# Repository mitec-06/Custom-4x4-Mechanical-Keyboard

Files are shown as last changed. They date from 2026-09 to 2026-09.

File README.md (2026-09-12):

# Custom 4x4 Keyboard PCB Design

This project is a custom 4x4 mechanical keyboard PCB featuring USB HID firmware on RP2040, addressable RGB LEDs (SK6812) driven via PIO state machine, rotary encoder brightness control, and HSV color animation functions.

## Functions

### Core Functions

- 16 keys arranged in a 4 x 4 matrix pattern.

- 6 key rollover - up to 6 simultaneous keypresses registered.

- USB HID keyboard output - It can work as a plug-and-play keyboard on any computer.

- Debouncing key detection - Prevents false or double triggers from a mechanical switch bounce.

- Diode per key - Diodes were included for every key in order to prevent ghosting.

### LED Functions
- Idle RGB ripple animation - Outward ripple effect starting from center rings cycling through the entire HSV color spectrum.

- Keypress-reactive LEDS - Animation switches to keypress mode when any key is pressed, returns to idle afterwards.

- Full HSV color transition - Smooth transition between red, orange, yellow, green, cyan, blue, magenta and back.

- Ring based animation - Three concentric rings with slight phase offset creating a ripple appearance.

- Brightness control - Using a rotary encoder, smooth brightness scaling from 0-100% applied uniformly to all LEDs.

- Brightness preserved across all animation modes, whether its idle or a key is being pressed.

### Encoder Functions 

- Clockwise rotation increases brightness, counterclockwise rotation decreases brightness.

- Hardware debouncing edge detection - Prevents any skips when rotating the encoder.

### Hardware Features 

- 3.3V to 5V level shifting for LED data signal via SN74LV1T34

- Daisy-chained SK6812 MINI-E LEDs driven via RP2040 PIO state machine.

- RP2040 PIO state machine - Dedicated programmable Input/Output handles precise WS2812 timing independent of CPU timing.

- WS2812 protocol followed to ensure correct latch reset timing.

- USB powered - single cable for both HID and power communication.

## Timeline

### April 2026 - May 2026

Primarily worked on keyboard research, and drafting the schematic and pcb. Once the pcb was finished, spent some time revising the placement of parts on the board to make sure that there were no shorts or awkward placements that would make assembly difficult.

Schematic

PCB Layout

### May 2026 - June 2026

Ordered the first batch of PCBs from PCBWay, and begun soldering the first prototype, however several hardware bugs prevented the LEDs from functioning properly, causing odd behavior, and allowing only the typing to work.

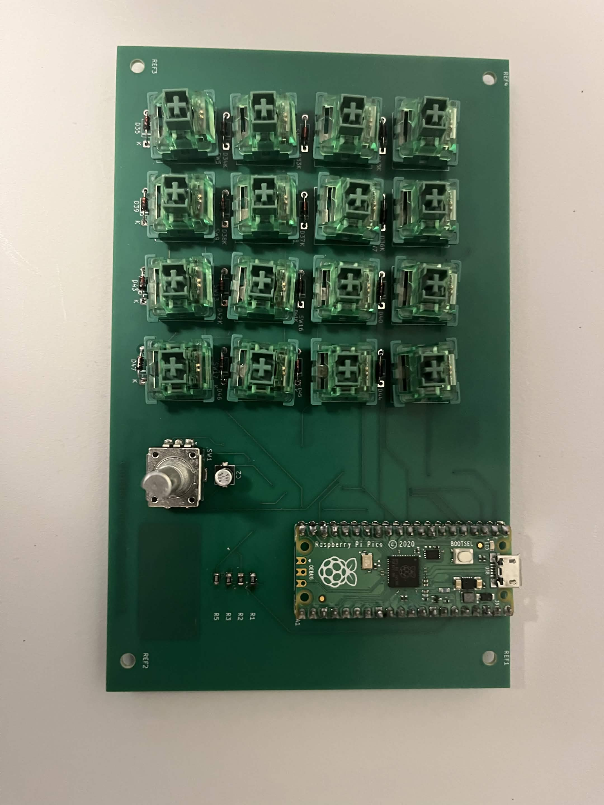
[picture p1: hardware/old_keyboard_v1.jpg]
First Prototype


### June 2026 - July 2026
Managed to get the first four LEDs of the board working, with the other 12 not functioning properly.

Extensively debugged several iterations of the board, ultimately finding that the DIN and DOUT pins on the SK6812 MINI-Es were swapped on the 5th-8th LEDs.

Because the keyboard follows a serpentine transmission of data where the signal of the next LED depends on the signal of the last LED, this broke the sequence for the rest of the LEDs.

Ultimately, the DIN/DOUT pins were finally oriented correctly, and a new batch of PCBs were ordered.

### July 2026 - August 2026

Assembled and soldered the new functioning PCBs, which finally had all 16 LEDs turn on properly. In this time period, the rest of the firmware was added, including the logic for the HSV color transition, the ring-like HSV color animation, the logic for the LED brightness dimming, etc.

In this time period, the case of the PCB was modelled using OnShape, and 3D printed, being assembled towards the end of this project, and ultimately yielding the final keyboard product. :)

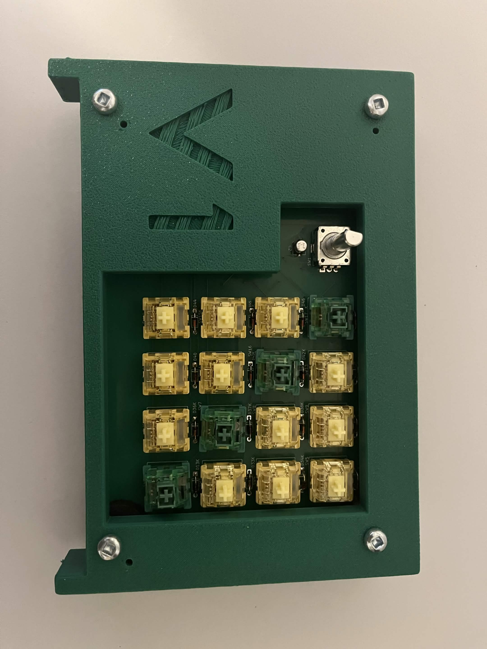
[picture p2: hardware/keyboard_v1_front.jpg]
Keyboard Front


## Future Improvements

- Most notably, while assembling/soldering check more frequently whether the parts assembled have the right voltage/behavior using tools such as oscilloscopes or multimeters.

- When hardware debugging, record previous symptoms of the build to ensure that the user assembling the PCB has the full picture, and might not confuse the actual cause of the bug for something else.

- Exercise more caution right before ordering PCBs, ensuring several times that the parts on the PCB have been wired correctly, even if it may pass the Design Rule Check.

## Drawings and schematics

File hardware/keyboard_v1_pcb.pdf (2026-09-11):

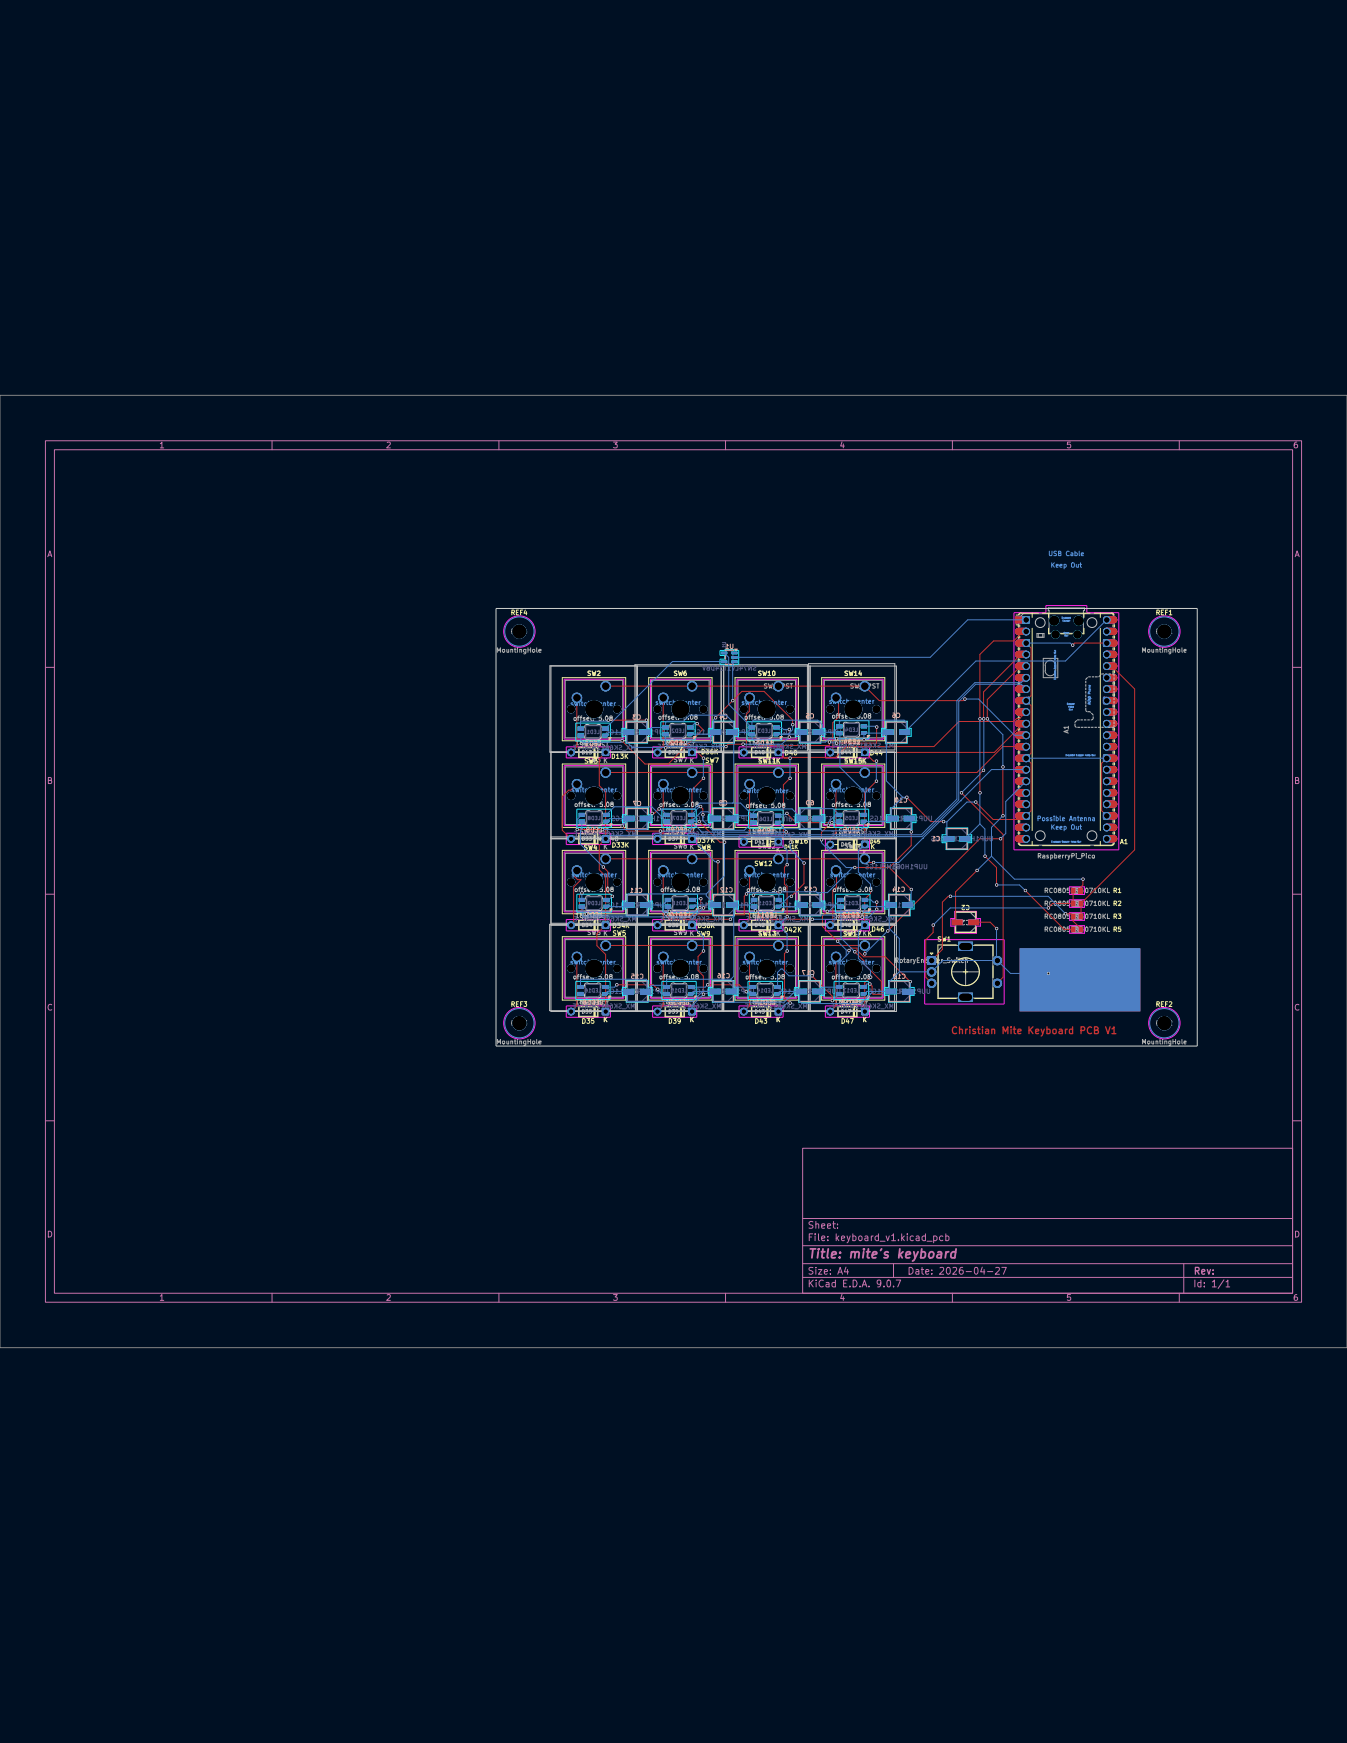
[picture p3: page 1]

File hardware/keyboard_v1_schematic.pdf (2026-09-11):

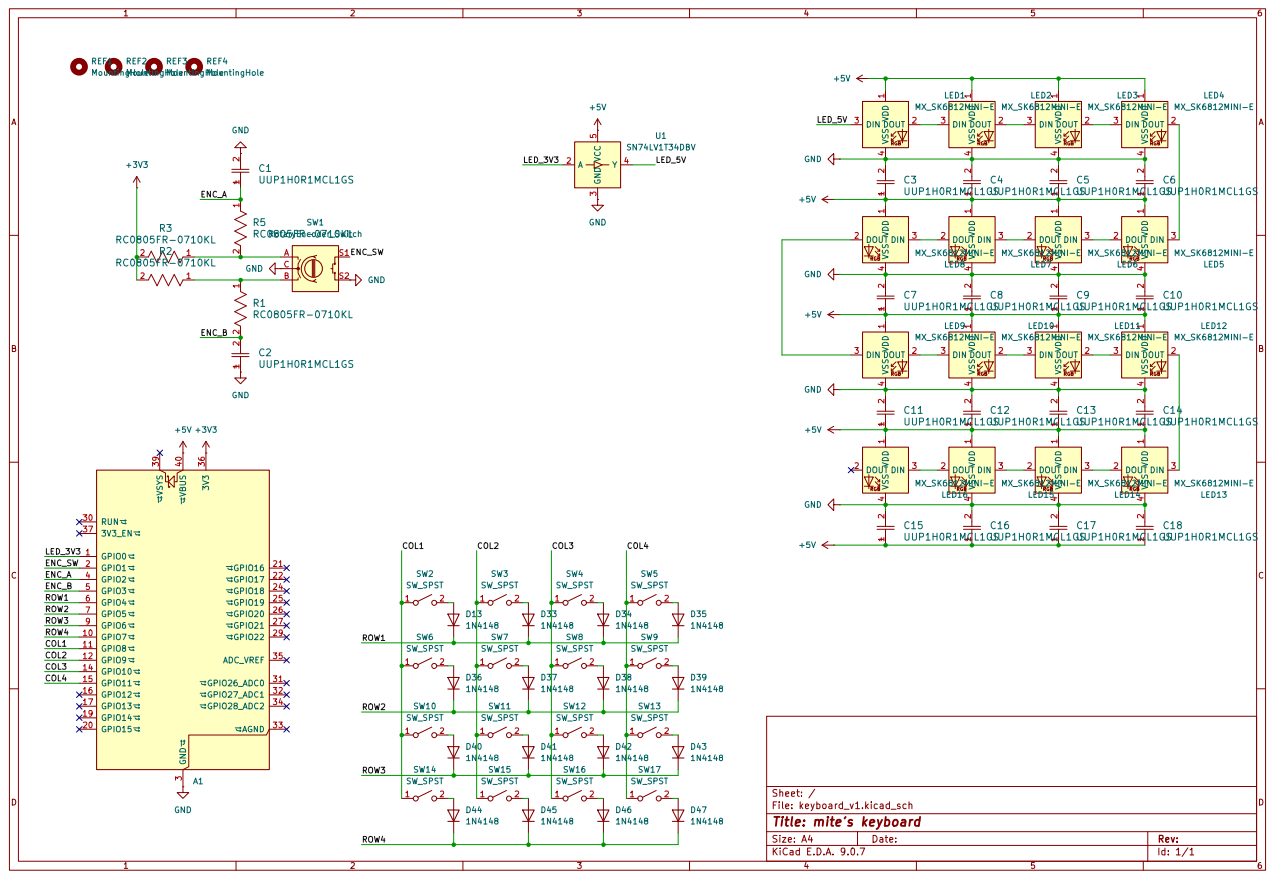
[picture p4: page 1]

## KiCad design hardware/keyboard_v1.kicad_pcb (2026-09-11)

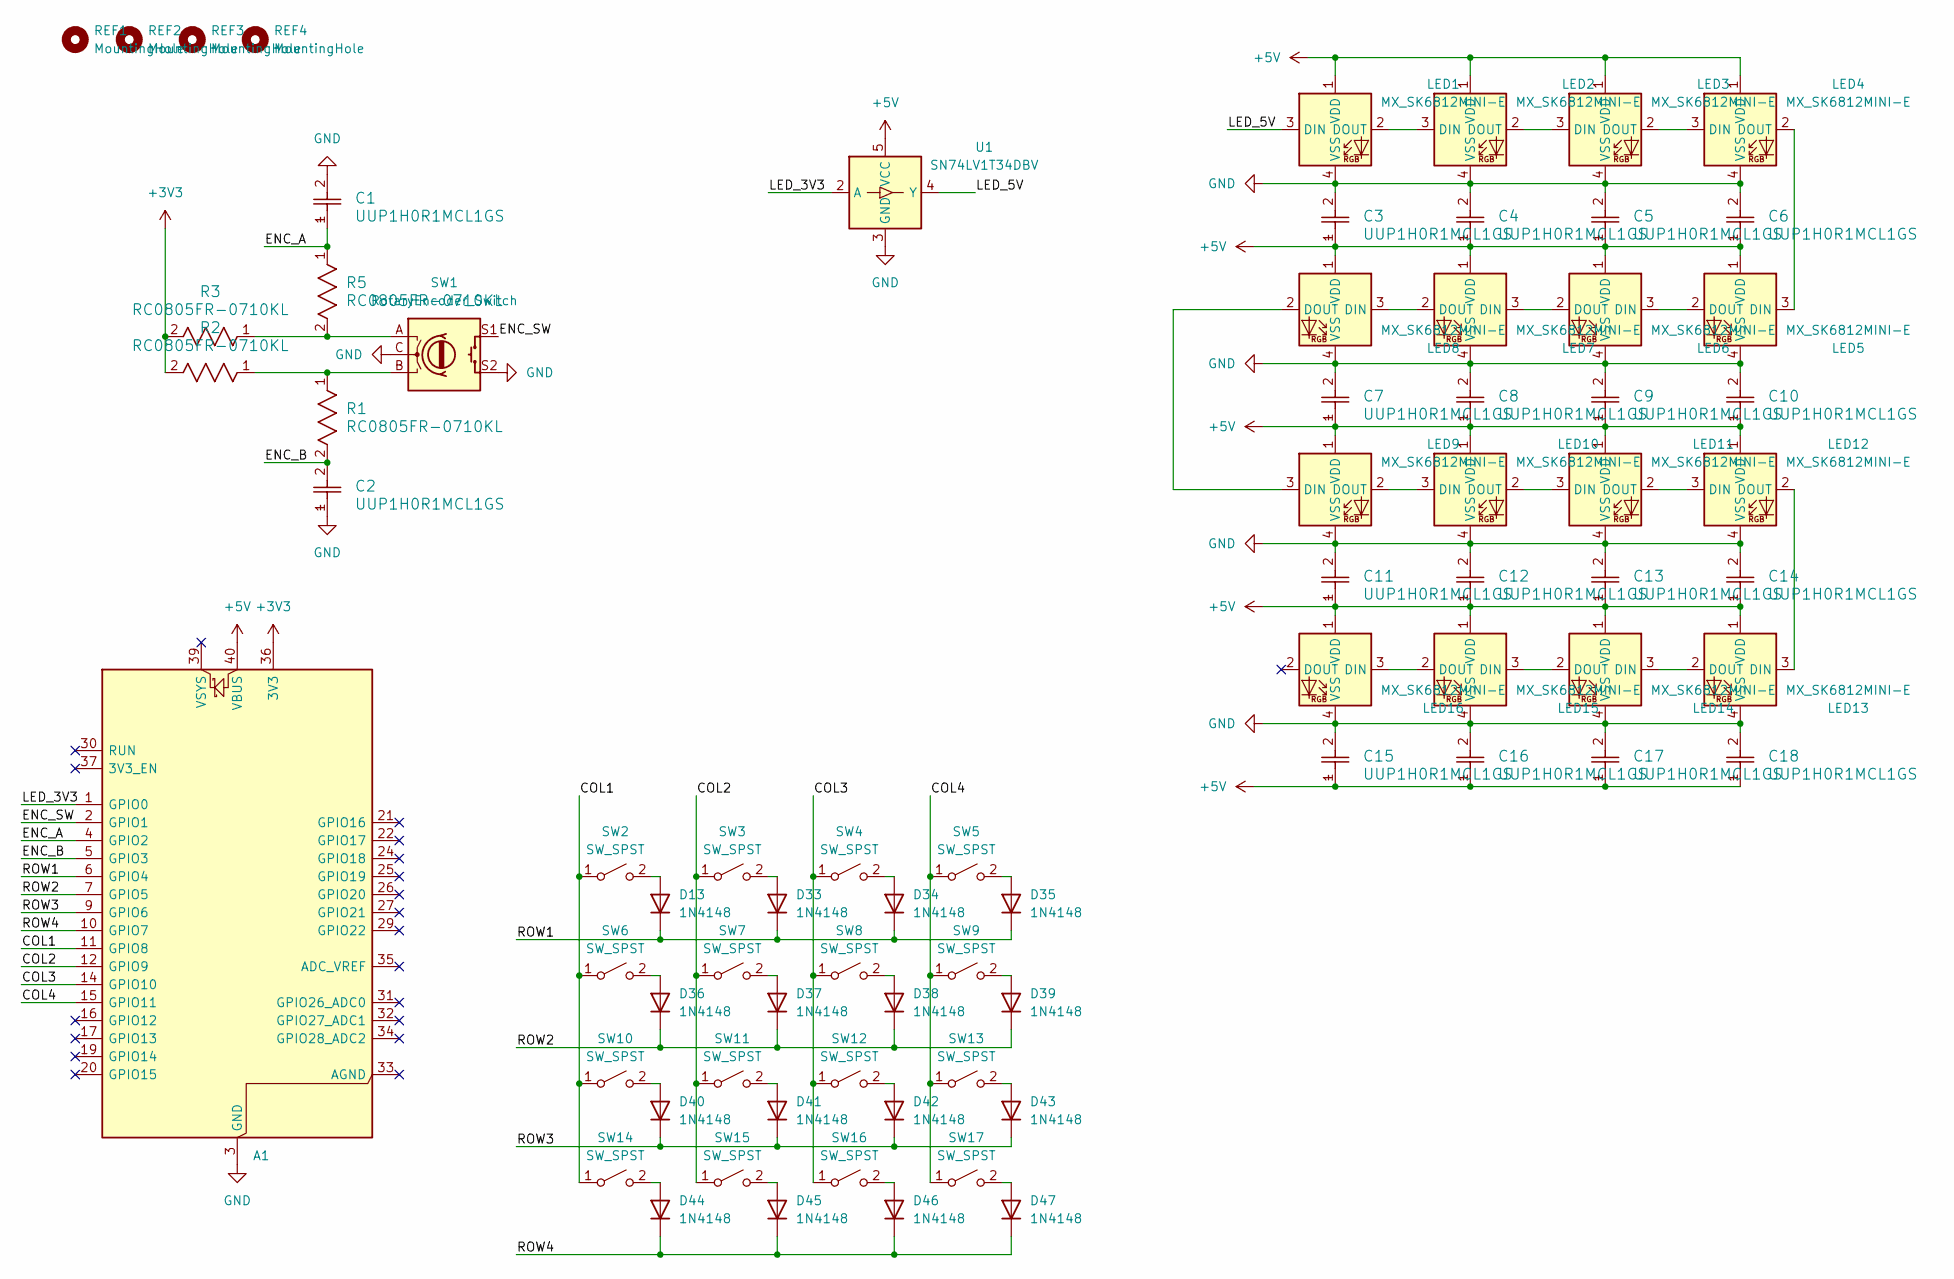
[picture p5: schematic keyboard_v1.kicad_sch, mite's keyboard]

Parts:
A1: RaspberryPi_Pico; RaspberryPi_Pico_Common_Unspecified
C1, C2, C3, C4, C5, C6, C7, C8, C9, C10, C11, C12, C13, C14, C15, C16, C17, C18: UUP1H0R1MCL1GS; CAP_UCD_4X5P8_NCH
D13, D33, D34, D35, D36, D37, D38, D39, D40, D41, D42, D43, D44, D45, D46, D47: 1N4148; D_DO-35_SOD27_P7.62mm_Horizontal
LED1, LED2, LED3, LED4, LED5, LED6, LED7, LED8, LED9, LED10, LED11, LED12, LED13, LED14, LED15, LED16: MX_SK6812MINI-E; LED_MX_6028R
R1, R2, R3, R5: RC0805FR-0710KL; RC0805N_YAG
REF1, REF2, REF3, REF4: MountingHole; MountingHole_3.2mm_M3
SW1: RotaryEncoder_Switch; RotaryEncoder_Alps_EC11E-Switch_Vertical_H20mm
SW2, SW3, SW4, SW5, SW6, SW7, SW8, SW9, SW10, SW11, SW12, SW13, SW14, SW15, SW16, SW17: SW_SPST; SW_Cherry_MX_1.00u_PCB
U1: SN74LV1T34DBV; SOT-23-5

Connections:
+3V3: A1.36 (3V3), R2.2, R3.2
+5V: A1.40 (VBUS), C3.1, C4.1, C5.1, C6.1, C7.1, C8.1, C9.1, C10.1, C11.1, C12.1, C13.1, C14.1, C15.1, C16.1, C17.1, C18.1, LED1.1 (VDD), LED2.1 (VDD), LED3.1 (VDD), LED4.1 (VDD), LED5.1 (VDD), LED6.1 (VDD), LED7.1 (VDD), LED8.1 (VDD), LED9.1 (VDD), LED10.1 (VDD), LED11.1 (VDD), LED12.1 (VDD), LED13.1 (VDD), LED14.1 (VDD), LED15.1 (VDD), LED16.1 (VDD), U1.5 (VCC)
/COL1: A1.11 (GPIO8), SW2.1 (A), SW6.1 (A), SW10.1 (A), SW14.1 (A)
/COL2: A1.12 (GPIO9), SW3.1 (A), SW7.1 (A), SW11.1 (A), SW15.1 (A)
/COL3: A1.14 (GPIO10), SW4.1 (A), SW8.1 (A), SW12.1 (A), SW16.1 (A)
/COL4: A1.15 (GPIO11), SW5.1 (A), SW9.1 (A), SW13.1 (A), SW17.1 (A)
/ENC_A: A1.4 (GPIO2), C1.1, R5.1
/ENC_B: A1.5 (GPIO3), C2.2, R1.2
/ENC_SW: A1.2 (GPIO1), SW1.S1
/LED_3V3: A1.1 (GPIO0), U1.2 (A)
/LED_5V: LED1.3 (DIN), U1.4 (Y)
/ROW1: A1.6 (GPIO4), D13.1 (K), D33.1 (K), D34.1 (K), D35.1 (K)
/ROW2: A1.7 (GPIO5), D36.1 (K), D37.1 (K), D38.1 (K), D39.1 (K)
/ROW3: A1.9 (GPIO6), D40.1 (K), D41.1 (K), D42.1 (K), D43.1 (K)
/ROW4: A1.10 (GPIO7), D44.1 (K), D45.1 (K), D46.1 (K), D47.1 (K)
GND: A1.3 (GND), A1.8 (GND), A1.13 (GND), A1.18 (GND), A1.23 (GND), A1.28 (GND), A1.38 (GND), C1.2, C2.1, C3.2, C4.2, C5.2, C6.2, C7.2, C8.2, C9.2, C10.2, C11.2, C12.2, C13.2, C14.2, C15.2, C16.2, C17.2, C18.2, LED1.4 (VSS), LED2.4 (VSS), LED3.4 (VSS), LED4.4 (VSS), LED5.4 (VSS), LED6.4 (VSS), LED7.4 (VSS), LED8.4 (VSS), LED9.4 (VSS), LED10.4 (VSS), LED11.4 (VSS), LED12.4 (VSS), LED13.4 (VSS), LED14.4 (VSS), LED15.4 (VSS), LED16.4 (VSS), SW1.C, SW1.S2, U1.3 (GND)
unnamed: D13.2 (A), SW2.2 (B)
unnamed: D33.2 (A), SW3.2 (B)
unnamed: D34.2 (A), SW4.2 (B)
unnamed: D35.2 (A), SW5.2 (B)
unnamed: D36.2 (A), SW6.2 (B)
unnamed: D37.2 (A), SW7.2 (B)
unnamed: D38.2 (A), SW8.2 (B)
unnamed: D39.2 (A), SW9.2 (B)
unnamed: D40.2 (A), SW10.2 (B)
unnamed: D41.2 (A), SW11.2 (B)
unnamed: D42.2 (A), SW12.2 (B)
unnamed: D43.2 (A), SW13.2 (B)
unnamed: D44.2 (A), SW14.2 (B)
unnamed: D45.2 (A), SW15.2 (B)
unnamed: D46.2 (A), SW16.2 (B)
unnamed: D47.2 (A), SW17.2 (B)
unnamed: LED1.2 (DOUT), LED2.3 (DIN)
unnamed: LED2.2 (DOUT), LED3.3 (DIN)
unnamed: LED3.2 (DOUT), LED4.3 (DIN)
unnamed: LED4.2 (DOUT), LED5.3 (DIN)
unnamed: LED5.2 (DOUT), LED6.3 (DIN)
unnamed: LED6.2 (DOUT), LED7.3 (DIN)
unnamed: LED7.2 (DOUT), LED8.3 (DIN)
unnamed: LED8.2 (DOUT), LED9.3 (DIN)
unnamed: LED9.2 (DOUT), LED10.3 (DIN)
unnamed: LED10.2 (DOUT), LED11.3 (DIN)
unnamed: LED11.2 (DOUT), LED12.3 (DIN)
unnamed: LED12.2 (DOUT), LED13.3 (DIN)
unnamed: LED13.2 (DOUT), LED14.3 (DIN)
unnamed: LED14.2 (DOUT), LED15.3 (DIN)
unnamed: LED15.2 (DOUT), LED16.3 (DIN)
unnamed: R1.1, R2.1, SW1.B
unnamed: R3.1, R5.2, SW1.A

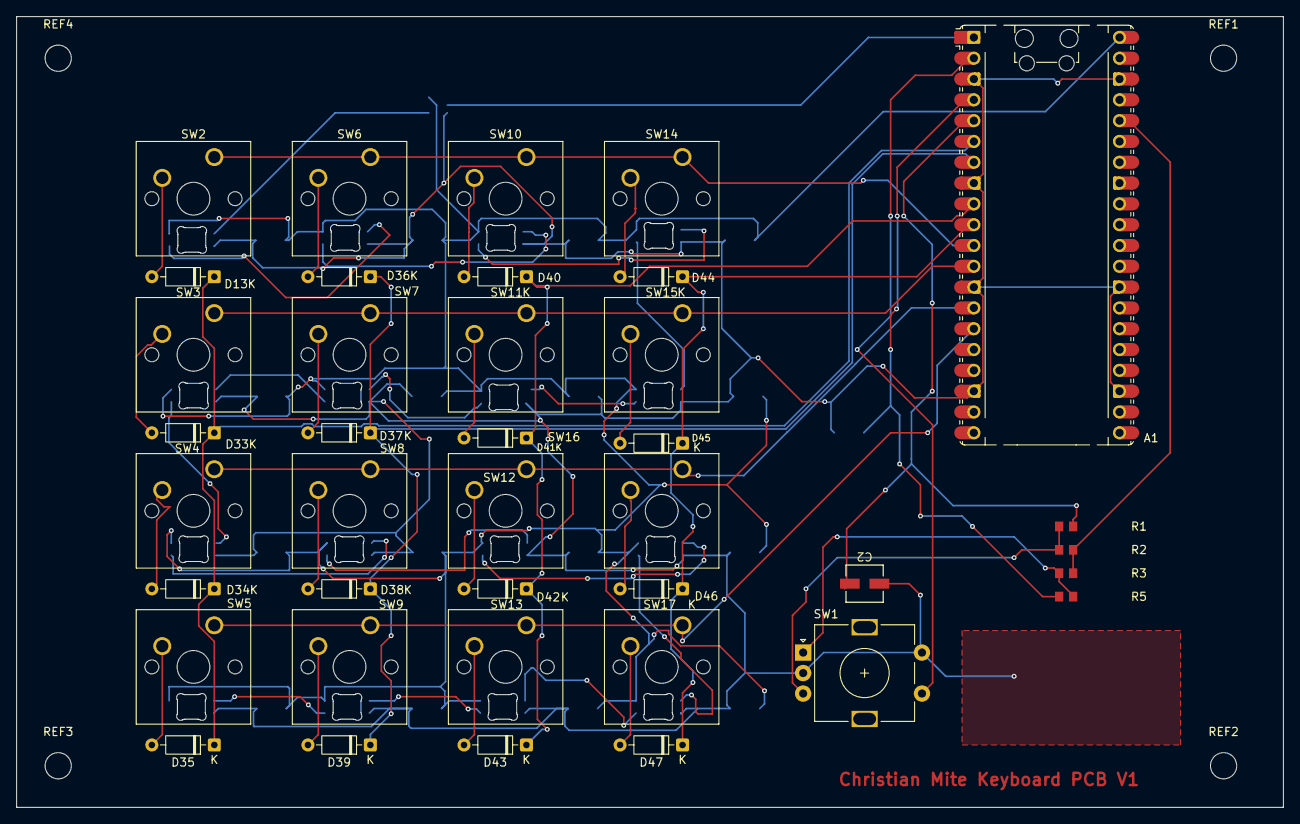
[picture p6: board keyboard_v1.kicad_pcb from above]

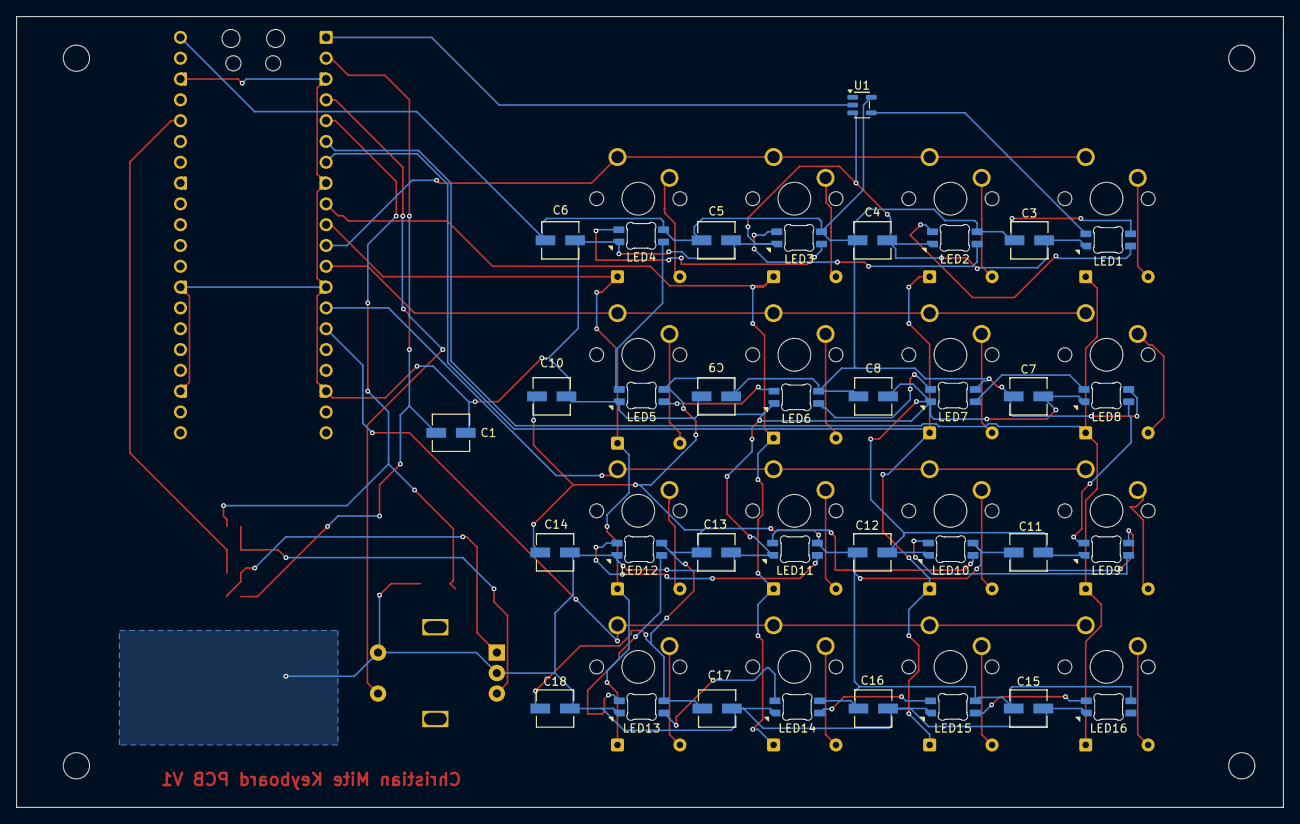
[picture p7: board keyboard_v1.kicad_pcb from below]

Board: 2 copper layers, 154.6 x 96.5 mm, 77 parts (34 on the bottom side), 49 nets.

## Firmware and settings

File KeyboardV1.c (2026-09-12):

#include <stdio.h>
#include <stdbool.h>
#include "pico/stdlib.h"
#include "tusb_config.h"
#include "tusb.h"
#include "ws2812.pio.h"
#include "hardware/pio.h"

void pin_setup(void);
void scan_matrix_and_report(void);
void led_turn();
void put_pixel(PIO pio, uint sm, uint32_t pixel_grb);
void led_ALL_ON();
void led_ONE_ON();
void LED_BRIGHTNESS();
void without_touch();
uint32_t hsv_to_rgb(int hue);
bool isLedsOff();

bool key_tracking[4][4] = {false};
uint8_t modified = 0;

// define keymap here, declare const uint8_t keymap[4][4] = {...} HID_KEY_A, HID_KEY_B, 
// also define a local 6 byte storage array to track which keys are being sent to the computer 
uint8_t active_keys[6] = {0};

static volatile int led_brightness = 50;

static volatile int adjusted_brightness = 0;

static volatile int hue = 0;


const uint ROW_PIN1 = 4;
const uint ROW_PIN2 = 5;
const uint ROW_PIN3 = 6;
const uint ROW_PIN4 = 7;
const uint COL_PIN1 = 8;
const uint COL_PIN2 = 9;
const uint COL_PIN3 = 10;
const uint COL_PIN4 = 11;

uint row_pins[4] = {ROW_PIN1, ROW_PIN2, ROW_PIN3, ROW_PIN4};

uint col_pins[4] = {COL_PIN1, COL_PIN2, COL_PIN3, COL_PIN4};

const uint8_t key_map[4][4] = {{HID_KEY_A, HID_KEY_B, HID_KEY_C, HID_KEY_D}, {HID_KEY_E, HID_KEY_F, HID_KEY_G, HID_KEY_H}, {HID_KEY_I, HID_KEY_J
, HID_KEY_K, HID_KEY_L}, {HID_KEY_M, HID_KEY_N, HID_KEY_O, HID_KEY_P}};

bool led_map[4][4] = {0};
static volatile bool matrix_changed = false;

const uint ENC_SW = 1;
const uint ENC_A = 2;
const uint ENC_B = 3;

#define LED_COUNT 16

uint32_t leds[LED_COUNT];

// add two helper functions, look through active keys, find the first slot that equals 0, set it to the scancode, and break
// the other helper function is looking through active keys, and finding the slot that equals the scancode, removing it and breaking


PIO pio = pio0;
uint sm = 0;


int main()
{
    stdio_init_all();
    tusb_init();
    uint offset = pio_add_program(pio, &ws2812_program);

    // set the pins as GPIO_PWM
    gpio_init(ENC_A);
    gpio_set_dir(ENC_A, GPIO_IN);
    gpio_pull_up(ENC_A);

    gpio_init(ENC_B);
    gpio_set_dir(ENC_B, GPIO_IN);
    gpio_pull_up(ENC_B);

    // redundant since two slices are already shared, but just to get the concept down
    
    // determines whether the matrix changed or not.
    pin_setup();

    

    ws2812_program_init(pio, sm, offset, 0, 800000, false);

    adjusted_brightness = (int)(led_brightness * 255.0/ 100.0);
    // initial brightness setup

    while (true) {

        // scanning is analyzed first, if the keyboard is in an idle state, without_touch() is called
        // else, led_turn is called, and tries to detect the rotary encoder turn...

        // a hardware delay of 5 seconds is also implemented to make sure that the rotary encoder and LEDs work without any bugs..
        // hue is also incremented here, and matrix_changed is reset to false after running all the functions

        tud_task();
        scan_matrix_and_report(); // where matrix_changed can be assigned false;
        LED_BRIGHTNESS();
        if (!isLedsOff()) without_touch();
        if (isLedsOff()) led_turn();
        sleep_ms(5);

        hue = (hue + 1) % 360;
        matrix_changed = false;
     
    }
}

// The following four functions are debugging functions used earlier to test whether
// the hardware was capable of turning on the LEDs in the first place.
bool isLedsOff(){
    for(int i = 0; i < 4; i++){
        for (int j = 0; j < 4; j++){
            if (led_map[i][j]) return true;
        }
    }
    return false;
}

void led_ONE_ON(){
    leds[0] = (255 << 16);
    for (int i = 1; i < LED_COUNT; i++){
        leds[i] = 0x0;
    }

    for (int i = 0; i < LED_COUNT; i++){
        put_pixel(pio, sm, leds[i]);
    }
    sleep_us(100);
}

void led_ALL_ON(){

    for (int i = 0; i < LED_COUNT; i++){
        leds[i] = (adjusted_brightness << 16) | (adjusted_brightness << 8) | (adjusted_brightness << 0);
    }
    for (int i = 0; i < LED_COUNT; i++){
        put_pixel(pio, sm, leds[i]);
    }
    sleep_us(100);
}
void led_turn(){
    for (int i = 0; i < LED_COUNT; i++){
        leds[i] = 0x0;
    }

    for (int r = 0; r < 4; r++){
        for (int c = 0; c < 4; c++){
            int index = (c % 2 == 0) ? 4 * c + r : 4 * c + (3 - r);
            if (led_map[r][c]){
               leds[index] = hsv_to_rgb(hue % 360);
            } 
        }
    }
    
    for (int i = 0; i < LED_COUNT; i++){
        put_pixel(pio, sm, leds[i]);
    }
    sleep_us(100);
}

void without_touch(){
    int offset = 15;

    // Ring system

    // ring1, innermost 4 leds

    leds[5] = hsv_to_rgb(hue % 360);
    leds[6] = hsv_to_rgb(hue % 360);
    leds[9] = hsv_to_rgb(hue % 360);
    leds[10] = hsv_to_rgb(hue % 360);

    // ring 2, next outward 8 leds

    leds[1] = hsv_to_rgb((hue-offset + 360) % 360);
    leds[2] = hsv_to_rgb((hue-offset + 360) % 360);
    leds[4] = hsv_to_rgb((hue-offset + 360) % 360);
    leds[8] = hsv_to_rgb((hue-offset + 360) % 360);
    leds[7] = hsv_to_rgb((hue-offset + 360) % 360);
    leds[11] = hsv_to_rgb((hue-offset + 360) % 360);
    leds[13] = hsv_to_rgb((hue-offset + 360) % 360);
    leds[14] = hsv_to_rgb((hue-offset + 360) % 360);

    // ring 3, the corners of the keyboard

    leds[0] = hsv_to_rgb((hue - (2 * offset) + 360) % 360);
    leds[3] = hsv_to_rgb((hue - (2 * offset) + 360) % 360);
    leds[12] = hsv_to_rgb((hue - (2 * offset) + 360) % 360);
    leds[15] = hsv_to_rgb((hue - (2 * offset) + 360) % 360);

    for (int i = 0; i < LED_COUNT; i++){
        put_pixel(pio, sm, leds[i]);
    }
}

uint32_t hsv_to_rgb(int hue){

// if hue is less than zero, pure red is sent to the leds
if (hue < 0) return (adjusted_brightness << 16) | (0 << 8) | (0 << 0);;
int segment = hue / 60;
int remainder = hue % 60;

int rising = remainder * 255/60;
int falling = (255 - remainder * 255/60);


// based on what segment the hue calculates to be, changes which color byte is losing/gaining value, creating a cycle.
if (segment == 0) return (adjusted_brightness << 16) | ((adjusted_brightness * rising / 255) << 8) | (0 << 0);
else if (segment == 1) return ((adjusted_brightness * falling / 255) << 16) | (adjusted_brightness << 8) | (0 << 0);
else if (segment == 2) return (0 << 16) | (adjusted_brightness << 8) | ((adjusted_brightness * rising / 255) << 0);
else if (segment == 3) return (0 << 16) | ((adjusted_brightness * falling / 255) << 8) | (adjusted_brightness << 0);
else if (segment == 4) return ((adjusted_brightness * rising / 255) << 16) | (0 << 8) | (adjusted_brightness << 0);
else return (adjusted_brightness << 16) | (0 << 8) | ((adjusted_brightness * falling / 255) << 0);
}

void LED_BRIGHTNESS(){
    // will prolly add code for ENC_SW
    // add code..

    static bool prev_enc_a = true;

    bool first_state = gpio_get(ENC_A);

    // make sure that ENC_A isint turned on
    if (prev_enc_a && !first_state){
        // 5 ms sleep for debouncing VERY IMPORTANT, WILL NOT RUN PROPERLY OTHERWISE
        sleep_ms(1);
        // checks one last time to make sure that ENC_A isint on
        if (!gpio_get(ENC_A)){
        // gpio_xor_mask(1 << 25); used for testing but pretty useless tbh
        bool other_state = gpio_get(ENC_B);
        // if A is off but B is ON, then its going CW
        if (other_state){
            if (led_brightness == 0){
            led_brightness = 0;
            }
            else led_brightness--; // CCW
        } else { // if B is OFF as well, then that means that A was the last to go, and its going CW, so led_brightness goes up.
            if (led_brightness == 100) {
            led_brightness = 100;
            }
            else led_brightness++; // CW
        }
        // calculate for adjusted brightness, it is cast into an int and then sent for the led to change its brightness
        adjusted_brightness = (int)(led_brightness * 255.0/ 100.0);
        }
    }

    prev_enc_a = first_state;
    
}

void pin_setup(){
// configure the output/input of each, ex is col output or row input, gpio_init(..)

    for (int i = 0; i < 4; i++){
        gpio_init(row_pins[i]);
        gpio_init(col_pins[i]);
    }
    // then set all the columns to pull up in order make all the signals equal to 1, if there is a 0, then a key is pressed.
    // gpio_pull_up(..)

    for (int i = 0; i < 4; i++){
        gpio_pull_up(col_pins[i]);
    }

    for (int i = 0; i < 4; i++){
        gpio_set_dir(row_pins[i], GPIO_OUT);
        gpio_set_dir(col_pins[i], GPIO_IN);
    }
}



void scan_matrix_and_report(){
    // keep this bool to check whether or not the matrix has been changed or not (add or remove a key)
       
        // Matrix Scanning Algorithm
        for (int r = 0; r < 4; r++){
            gpio_put(row_pins[r], 0);

            sleep_us(3);

            for (int c = 0; c < 4; c++){
                // if columns are pulled down, and its not already in key_tracking, that means its been chosen...
                if (!gpio_get(col_pins[c]) && !key_tracking[r][c]){
                    // Set key tracking to true. 
                    key_tracking[r][c] = true;
                    led_map[r][c] = true;
                    
                    // send the currently active map as scancode
                    uint8_t scancode = key_map[r][c];

                    matrix_changed = true;

                    // keeps a inventory of which keys are currently active, if a spot has been removed, then it inserts the newest code there..
                    for (int i = 0; i < 6; i++){
                        if (active_keys[i] == 0){
                            active_keys[i] = scancode;
                            break;
                        }
                    }

                    
                }
                else if (gpio_get(col_pins[c]) && key_tracking[r][c]) // if column pin has been released AND the key was already in the list of active keys..
                {
                    uint8_t scancode = key_map[r][c];
                    modified = 0;
                    for (int i = 0; i < 6; i++){
                        // find the specific key, and then set it as 0 so that another key can take it...
                        if (active_keys[i] == scancode){
                            active_keys[i] = 0;
                            break;
                        }
                    }

                    key_tracking[r][c] = false;
                    led_map[r][c] = false;
                    matrix_changed = true;
                }
            }

        gpio_put(row_pins[r], 1);
        sleep_us(3);
        }

    // if matrix has been changed, the key bundle is sent to the keyboard and displays yours truly
     if (matrix_changed)
    if (tud_hid_ready()){
        tud_hid_keyboard_report(0, modified, active_keys);
     } 
}


uint16_t tud_hid_get_report_cb(uint8_t instance, uint8_t report_id, hid_report_type_t report_type, uint8_t* buffer, uint16_t reqlen){
    (void) instance;
    (void) report_id;
    (void) report_type;
    (void) buffer;
    (void) reqlen;

    return 0;
}

void tud_hid_set_report_cb(uint8_t instance, uint8_t report_id, hid_report_type_t report_type, const uint8_t* buffer, uint16_t reqlen){
    (void) instance;
    (void) report_id;
    (void) report_type;
    (void) buffer;
    (void) reqlen;
}

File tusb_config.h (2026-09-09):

#ifndef _TUSB_CONFIG_H_
#define _TUSB_CONFIG_H_

// --- MCU Configuration ---
#define CFG_TUSB_MCU            OPT_MCU_RP2040
#define CFG_TUSB_OS             OPT_OS_PICO

// --- Device Configuration ---
#define CFG_TUSB_RHPORT0_MODE   (OPT_MODE_DEVICE | OPT_MODE_FULL_SPEED)
#define CFG_TUD_ENABLED         1
#define CFG_TUD_MAX_SPEED       OPT_MODE_DEFAULT_SPEED

// --- HID Class Configuration ---
#define CFG_TUD_HID             1
#define CFG_TUD_HID_EP_BUFSIZE  16  // Matches the 16-byte size in your descriptor

#endif // _TUSB_CONFIG_H_

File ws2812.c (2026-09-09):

/**
 * Copyright (c) 2020 Raspberry Pi (Trading) Ltd.
 *
 * SPDX-License-Identifier: BSD-3-Clause
 */

#include <stdio.h>
#include <stdlib.h>

#include "pico/stdlib.h"
#include "hardware/pio.h"
#include "hardware/clocks.h"
#include "ws2812.pio.h"

/**
 * NOTE:
 *  Take into consideration if your WS2812 is a RGB or RGBW variant.
 *
 *  If it is RGBW, you need to set IS_RGBW to true and provide 4 bytes per 
 *  pixel (Red, Green, Blue, White) and use urgbw_u32().
 *
 *  If it is RGB, set IS_RGBW to false and provide 3 bytes per pixel (Red,
 *  Green, Blue) and use urgb_u32().
 *
 *  When RGBW is used with urgb_u32(), the White channel will be ignored (off).
 *
 */
#define IS_RGBW false
#define NUM_PIXELS 150

#ifdef PICO_DEFAULT_WS2812_PIN
#define WS2812_PIN PICO_DEFAULT_WS2812_PIN
#else
// default to pin 2 if the board doesn't have a default WS2812 pin defined
#define WS2812_PIN 2
#endif

// Check the pin is compatible with the platform
#if WS2812_PIN >= NUM_BANK0_GPIOS
#error Attempting to use a pin>=32 on a platform that does not support it
#endif

void put_pixel(PIO pio, uint sm, uint32_t pixel_grb) {
    pio_sm_put_blocking(pio, sm, pixel_grb << 8u);
}

static inline uint32_t urgb_u32(uint8_t r, uint8_t g, uint8_t b) {
    return
            ((uint32_t) (r) << 8) |
            ((uint32_t) (g) << 16) |
            (uint32_t) (b);
}

static inline uint32_t urgbw_u32(uint8_t r, uint8_t g, uint8_t b, uint8_t w) {
    return
            ((uint32_t) (r) << 8) |
            ((uint32_t) (g) << 16) |
            ((uint32_t) (w) << 24) |
            (uint32_t) (b);
}

void pattern_snakes(PIO pio, uint sm, uint len, uint t) {
    for (uint i = 0; i < len; ++i) {
        uint x = (i + (t >> 1)) % 64;
        if (x < 10)
            put_pixel(pio, sm, urgb_u32(0xff, 0, 0));
        else if (x >= 15 && x < 25)
            put_pixel(pio, sm, urgb_u32(0, 0xff, 0));
        else if (x >= 30 && x < 40)
            put_pixel(pio, sm, urgb_u32(0, 0, 0xff));
        else
            put_pixel(pio, sm, 0);
    }
}

void pattern_random(PIO pio, uint sm, uint len, uint t) {
    if (t % 8)
        return;
    for (uint i = 0; i < len; ++i)
        put_pixel(pio, sm, rand());
}

void pattern_sparkle(PIO pio, uint sm, uint len, uint t) {
    if (t % 8)
        return;
    for (uint i = 0; i < len; ++i)
        put_pixel(pio, sm, rand() % 16 ? 0 : 0xffffffff);
}

void pattern_greys(PIO pio, uint sm, uint len, uint t) {
    uint max = 100; // let's not draw too much current!
    t %= max;
    for (uint i = 0; i < len; ++i) {
        put_pixel(pio, sm, t * 0x10101);
        if (++t >= max) t = 0;
    }
}

typedef void (*pattern)(PIO pio, uint sm, uint len, uint t);
const struct {
    pattern pat;
    const char *name;
} pattern_table[] = {
        {pattern_snakes,  "Snakes!"},
        {pattern_random,  "Random data"},
        {pattern_sparkle, "Sparkles"},
        {pattern_greys,   "Greys"},
};

/*
int main() {
    //set_sys_clock_48();
    stdio_init_all();
    printf("WS2812 Smoke Test, using pin %d\n", WS2812_PIN);

    // todo get free sm
    PIO pio;
    uint sm;
    uint offset;

    // This will find a free pio and state machine for our program and load it for us
    // We use pio_claim_free_sm_and_add_program_for_gpio_range (for_gpio_range variant)
    // so we will get a PIO instance suitable for addressing gpios >= 32 if needed and supported by the hardware
    bool success = pio_claim_free_sm_and_add_program_for_gpio_range(&ws2812_program, &pio, &sm, &offset, WS2812_PIN, 1, true);
    hard_assert(success);

    ws2812_program_init(pio, sm, offset, WS2812_PIN, 800000, IS_RGBW);

    int t = 0;
    while (1) {
        int pat = rand() % count_of(pattern_table);
        int dir = (rand() >> 30) & 1 ? 1 : -1;
        puts(pattern_table[pat].name);
        puts(dir == 1 ? "(forward)" : "(backward)");
        for (int i = 0; i < 1000; ++i) {
            pattern_table[pat].pat(pio, sm, NUM_PIXELS, t);
            sleep_ms(10);
            t += dir;
        }
    }

    // This will free resources and unload our program
    pio_remove_program_and_unclaim_sm(&ws2812_program, pio, sm, offset);
}
*/

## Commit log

2026-09-11 Revise README for keyboard PCB project details
    Updated project description with general features.
2026-09-11 New hardware folder added.
    [keyboard_v1.kicad_pcb, keyboard_v1.kicad_sch]
2026-09-11 Added pictures of the PCB and schematic to the hardware folder.
2026-09-11 The previous PCB Layout image was cut off, so a clearer image replaced it.
2026-09-11 Previous PCB Layout image was lower quality, so a clearer image replaced it.
